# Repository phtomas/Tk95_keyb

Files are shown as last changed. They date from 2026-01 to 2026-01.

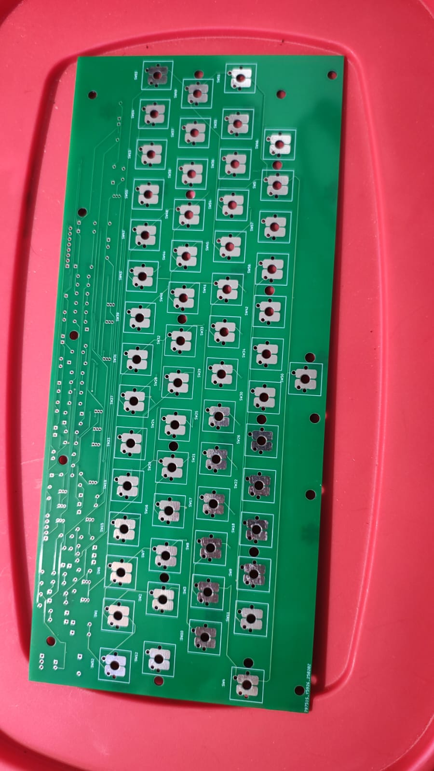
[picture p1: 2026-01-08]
keyb95_mx.jpeg

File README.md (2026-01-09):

Gerbers files to produce TK95 keyboard boards to substitute membranes. you can use original acetate and upper membrane to make contact for the keys, since at least key contact points are working. Or you can coat that points with some conduct ink or even stick some conduct material in that or use MX switches for a complete mechanical keyboard.

Based on Don Superfo schematics. original at: https://www.pcbway.com/project/shareproject/ZX_Spectrum_Keyboard_V2_14d9c665.html

Special thanks to Alexandre Simonka who has sponsered this project and Marlos Vasconcelos for moral support. Many thanks my friends.

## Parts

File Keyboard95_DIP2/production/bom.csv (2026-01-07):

Designator | Footprint | Quantity | Value | LCSC Part #
C1 | CP_Radial_D5.0mm_P2.50mm | 1 | 100uF
D1, D10, D11, D12, D13, D14, D15, D16, D17, D18, D19, D2, D20, D21, D22, D23, D24, D25, D26, D27, D28, D29, D3, D30, D31, D32, D4, D5, D6, D7, D8, D9 | D_DO-35_SOD27_P7.62mm_Horizontal | 32 | 1N4148
D33 | D_A-405_P7.62mm_Horizontal | 1 | 5v1
J1 | PinHeader_1x03_P2.54mm_Vertical | 1 | Conn_01x03_Pin
J2 | PinHeader_1x05_P2.54mm_Vertical | 1 | Conn_01x05_Pin
J3 | PinHeader_1x08_P2.54mm_Vertical | 1 | Conn_01x08_Pin
Q1, Q10, Q11P1, Q12M1, Q13N1, Q14O1, Q2, Q3, Q4, Q5, Q6, Q7, Q8, Q9 | TO-92_Inline | 14 | BC548
R1, R13, R14, R15, R16, R2, R21, R22, R23, R24, R3, R4, R5, R6 | R_Box_L8.4mm_W2.5mm_P5.08mm | 14 | 1k
R10, R11, R12, R17, R18, R19, R20, R25, R26, R27, R28, R7, R8, R9 | R_Box_L8.4mm_W2.5mm_P5.08mm | 14 | 100k
SW1 | SW_SMD_key | 1 | SW_1
SW10 | SW_SMD_key | 1 | SW_EXT
SW11 | SW_SMD_key | 1 | SW_CPLOK
SW12 | SW_SMD_key | 1 | SW_GRAPH
SW13 | SW_SMD_key | 1 | SW_TRUE
SW14 | SW_SMD_key | 1 | SW_INV
SW15 | SW_SMD_key | 1 | SW_3
SW16 | SW_SMD_key | 1 | SW_E
SW17 | SW_SMD_key | 1 | SW_D
SW18 | SW_SMD_key | 1 | SW_X
SW19 | SW_SMD_key | 1 | SW_4
SW2 | SW_SMD_key | 1 | SW_Q
SW20 | SW_SMD_key | 1 | SW_R
SW21 | SW_SMD_key | 1 | SW_F
SW22 | SW_SMD_key | 1 | SW_C
SW23 | SW_SMD_key | 1 | SW_5
SW24 | SW_SMD_key | 1 | SW_T
SW25 | SW_SMD_key | 1 | SW_G
SW26 | SW_SMD_key | 1 | SW_V
SW27 | SW_SMD_key | 1 | SW_6
SW28 | SW_SMD_key | 1 | SW_Y
SW29 | SW_SMD_key | 1 | SW_H
SW3 | SW_SMD_key | 1 | SW_A
SW30 | SW_SMD_key | 1 | SW_B
SW31 | SW_SMD_key | 1 | SW_7
SW32 | SW_SMD_key | 1 | SW_U
SW33 | SW_SMD_key | 1 | SW_J
SW34 | SW_SMD_key | 1 | SW_N
SW35 | SW_SMD_key | 1 | SW_RiGhT
SW36 | SW_SMD_key | 1 | SW_LFT
SW37 | SW_SMD_key | 1 | SW_DWN
SW38 | SW_SMD_key | 1 | SW_UP
SW39 | SW_SMD_key | 1 | SW_8
SW4, SW5 | SW_SMD_key | 2 | SW_SHFT
SW40 | SW_SMD_key | 1 | SW_I
SW41 | SW_SMD_key | 1 | SW_K
SW42 | SW_SMD_key | 1 | SW_M
SW43 | SW_SMD_key | 1 | SW_9
SW44 | SW_SMD_key | 1 | SW_O
SW45 | SW_SMD_key | 1 | SW_L
SW46 | SW_SMD_key | 1 | SW_SYMB
SW47 | SW_SMD_key | 1 | SW_0
SW48 | SW_SMD_key | 1 | SW_P
SW49 | SW_SMD_key | 1 | SW_ENT
SW50 | SW_SMD_key | 1 | SW_SPC
SW51 | SW_SMD_key | 1 | SW_DEL
SW52 | SW_SMD_key | 1 | SW_EDT
SW53 | SW_SMD_key | 1 | SW_BRK
SW54 | SW_SMD_key | 1 | SW_dotvirg
SW55 | SW_SMD_key | 1 | SW_asp
SW56 | SW_SMD_key | 1 | SW_dot
SW57 | SW_SMD_key | 1 | SW_virg
SW6 | SW_SMD_key | 1 | SW_2
SW7 | SW_SMD_key | 1 | SW_W
SW8 | SW_SMD_key | 1 | SW_S
SW9 | SW_SMD_key | 1 | SW_Z

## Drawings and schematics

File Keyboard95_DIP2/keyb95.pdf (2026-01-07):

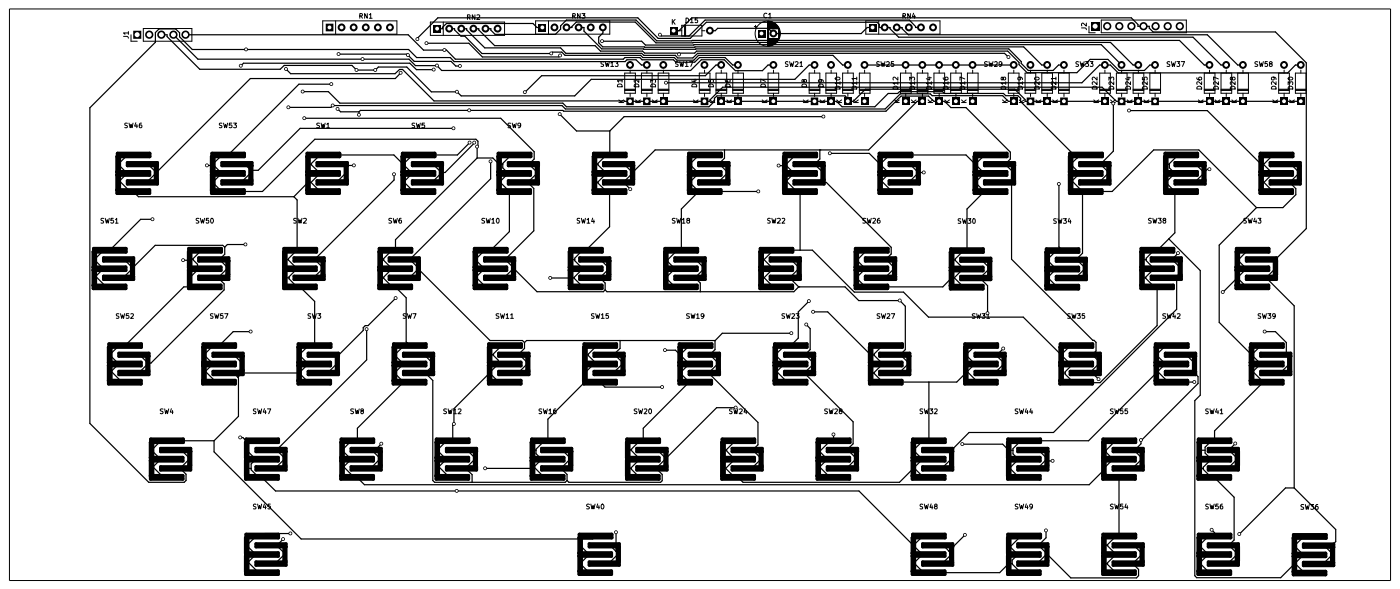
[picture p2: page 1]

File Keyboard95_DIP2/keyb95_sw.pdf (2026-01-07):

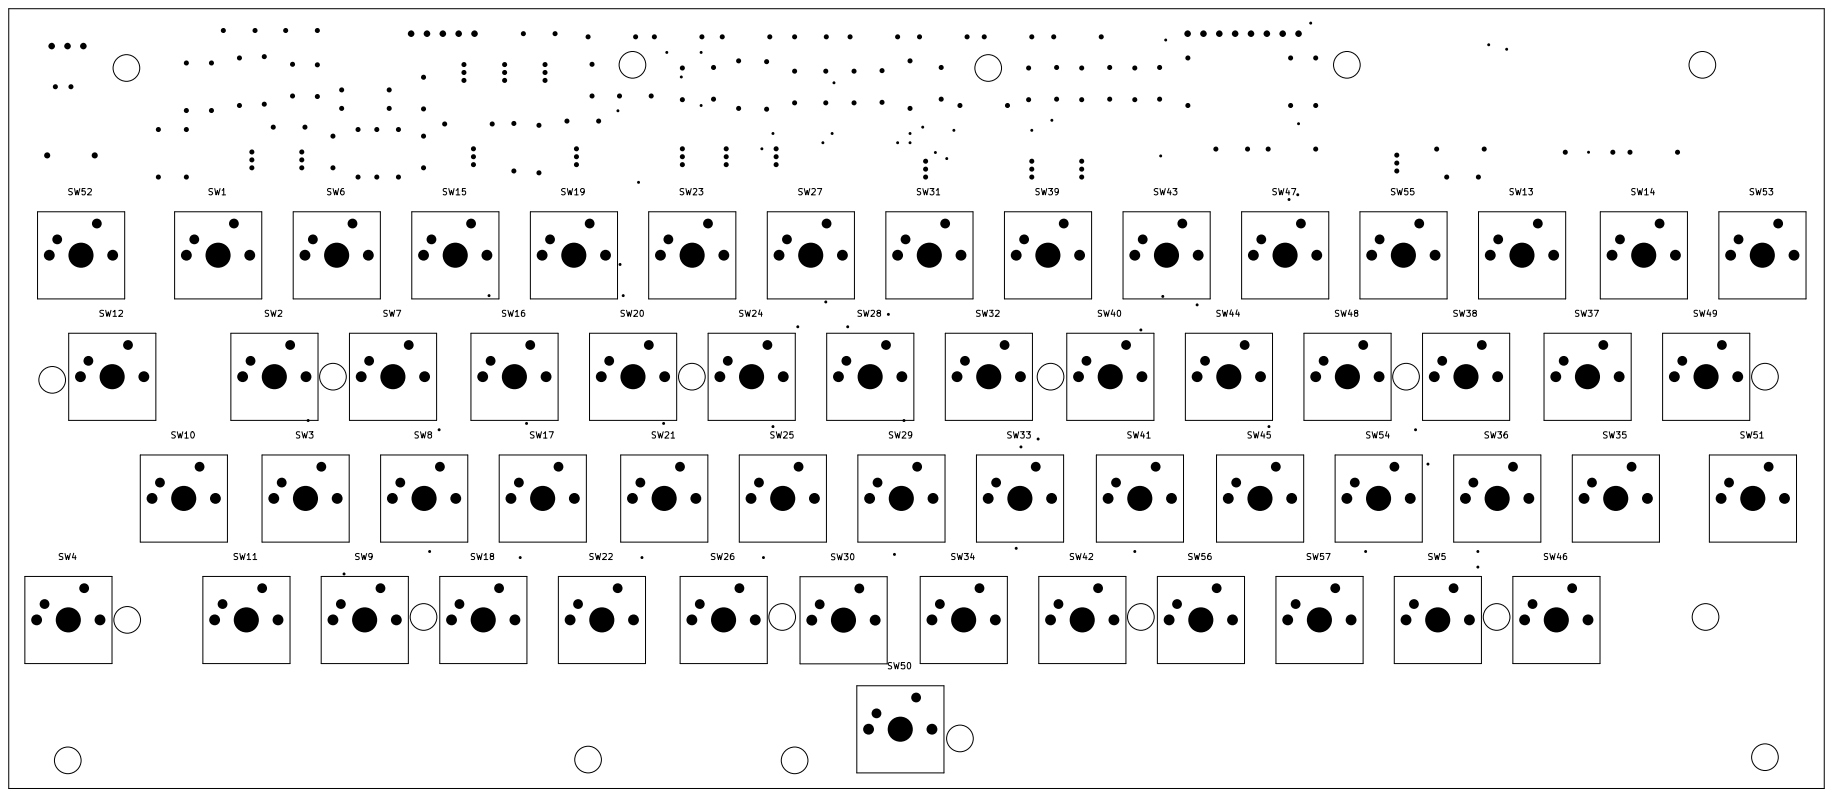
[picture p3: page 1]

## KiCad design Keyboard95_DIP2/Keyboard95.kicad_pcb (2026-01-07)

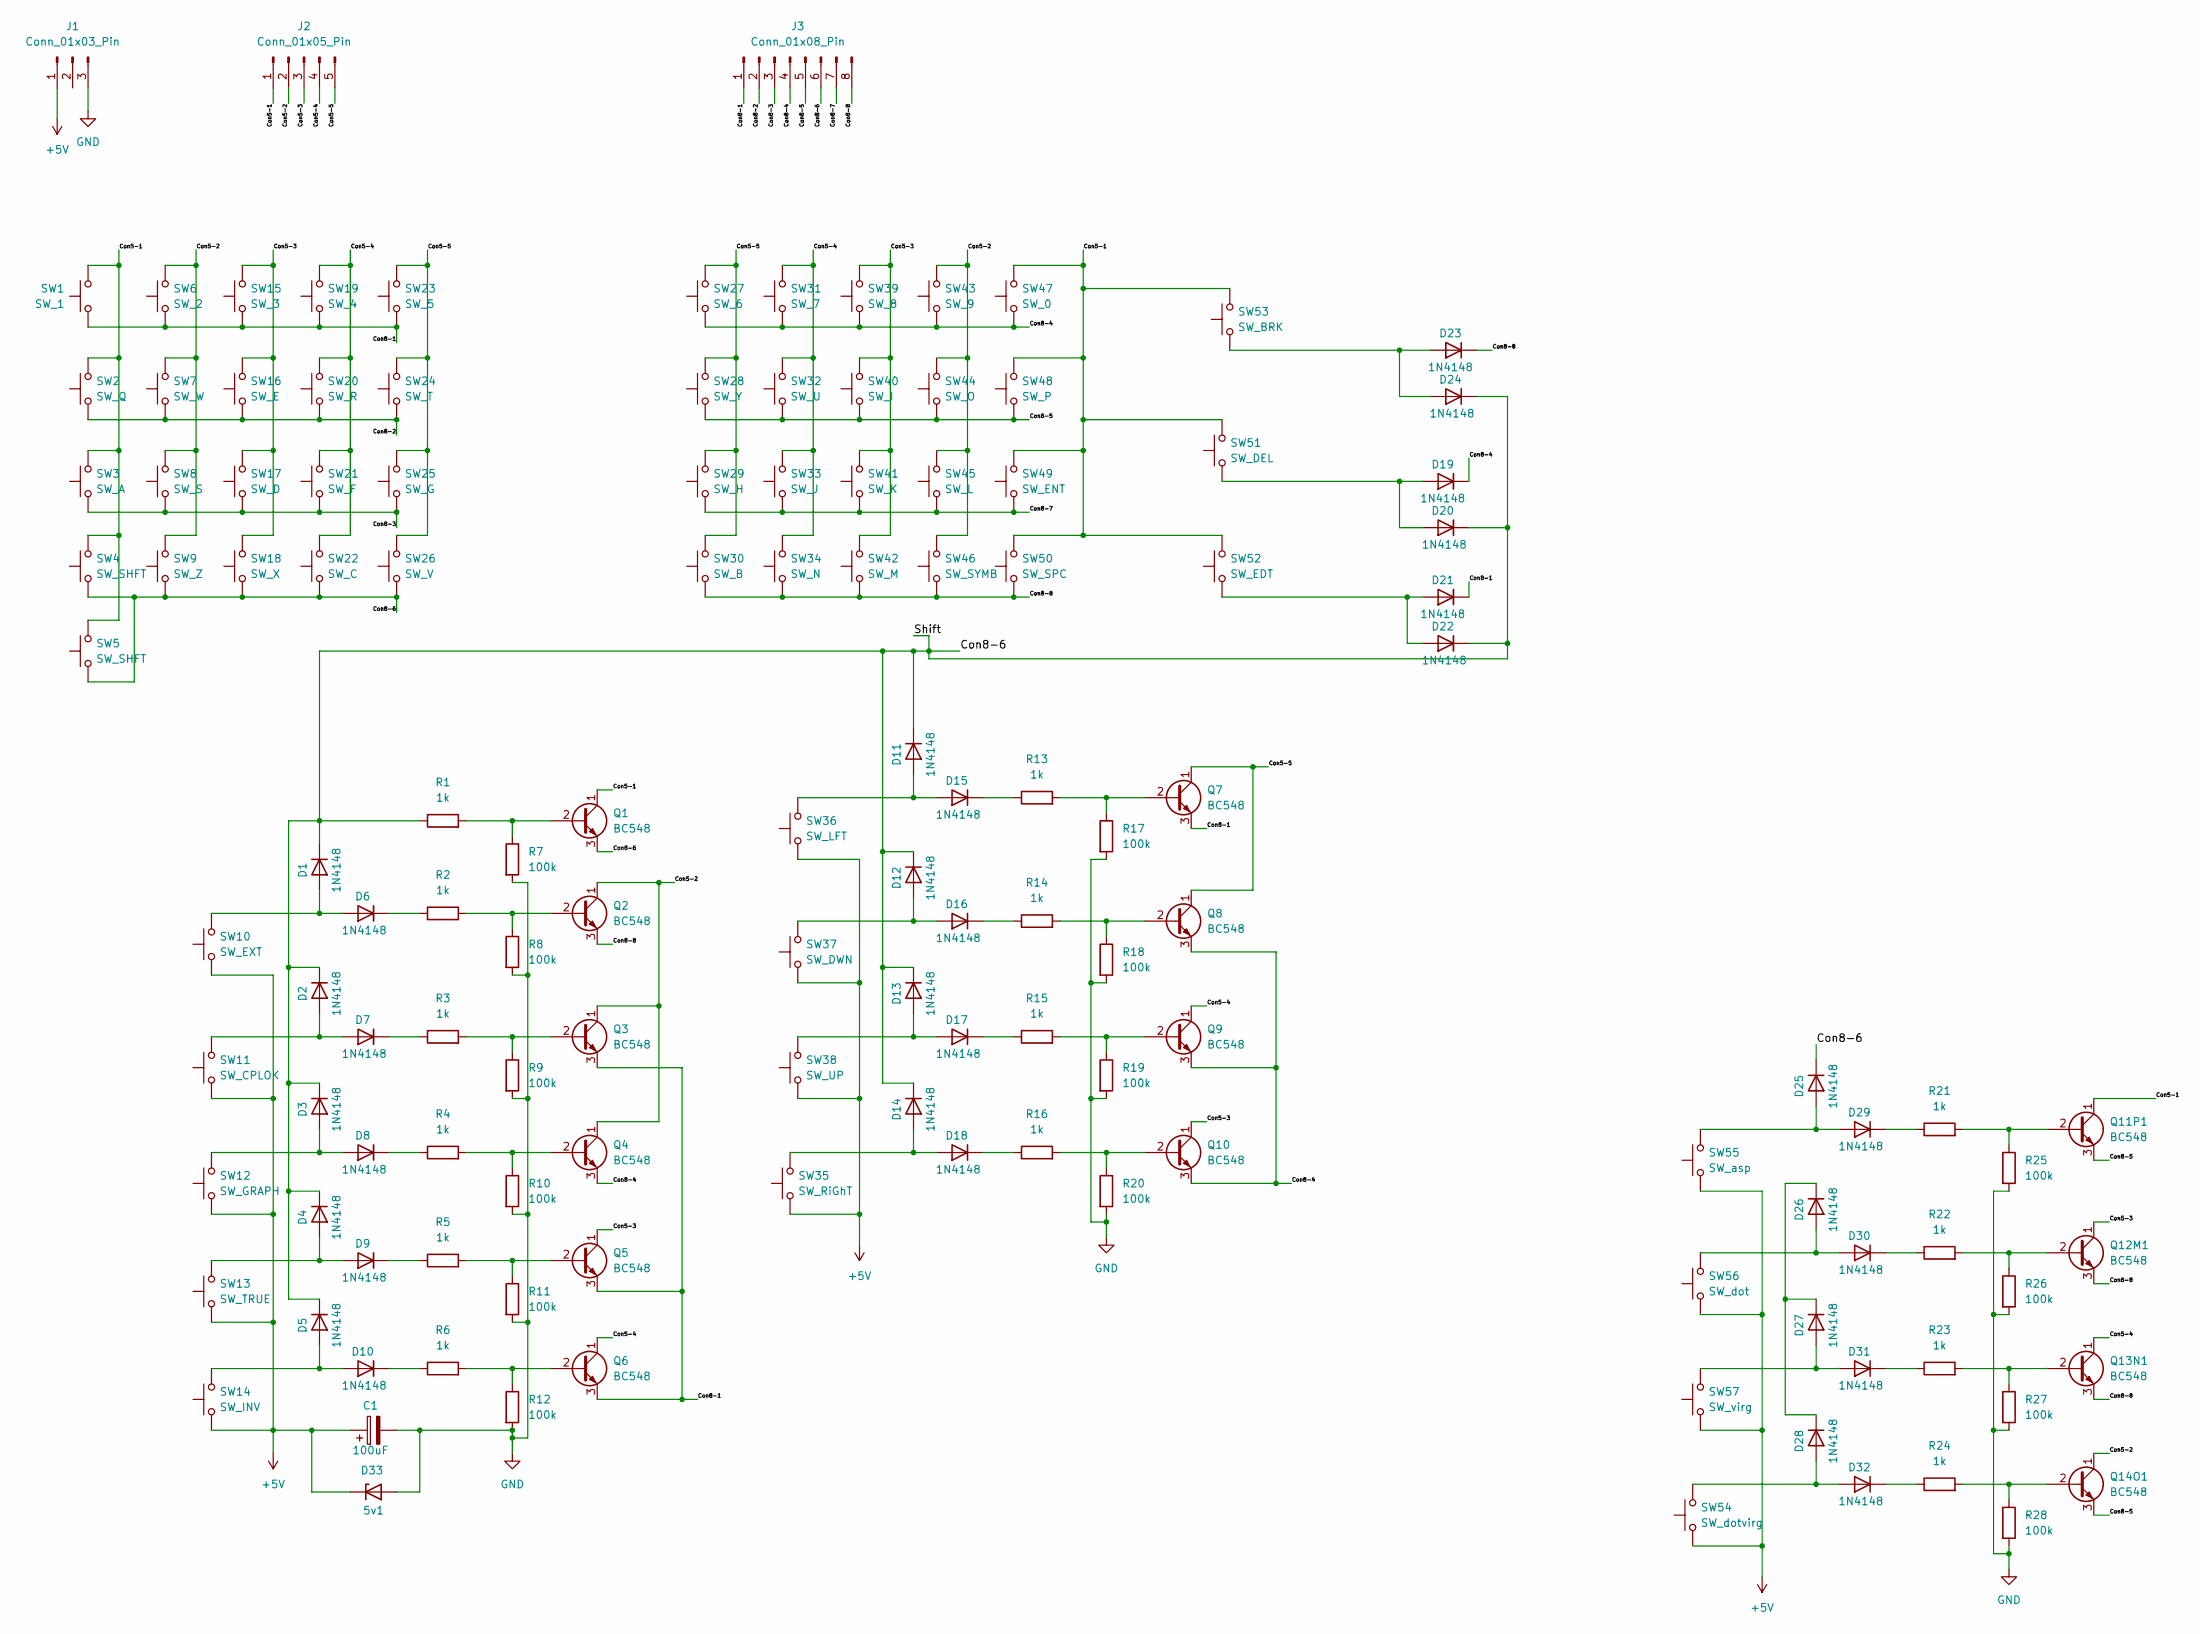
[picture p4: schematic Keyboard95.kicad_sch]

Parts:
C1: 100uF; CP_Radial_D5.0mm_P2.50mm
D1, D2, D3, D4, D5, D6, D7, D8, D9, D10, D11, D12, D13, D14, D15, D16, D17, D18, D19, D20, D21, D22, D23, D24, D25, D26, D27, D28, D29, D30, D31, D32: 1N4148; D_DO-35_SOD27_P7.62mm_Horizontal
D33: 5v1; D_A-405_P7.62mm_Horizontal
J1: Conn_01x03_Pin; PinHeader_1x03_P2.54mm_Vertical
J2: Conn_01x05_Pin; PinHeader_1x05_P2.54mm_Vertical
J3: Conn_01x08_Pin; PinHeader_1x08_P2.54mm_Vertical
Q1, Q2, Q3, Q4, Q5, Q6, Q7, Q8, Q9, Q10, Q11P1, Q12M1, Q13N1, Q14O1: BC548; TO-92_Inline
R1, R2, R3, R4, R5, R6, R13, R14, R15, R16, R21, R22, R23, R24: 1k; R_Box_L8.4mm_W2.5mm_P5.08mm
R7, R8, R9, R10, R11, R12, R17, R18, R19, R20, R25, R26, R27, R28: 100k; R_Box_L8.4mm_W2.5mm_P5.08mm
SW1: SW_1; SW_SMD_key
SW2: SW_Q; SW_SMD_key
SW3: SW_A; SW_SMD_key
SW4, SW5: SW_SHFT; SW_SMD_key
SW6: SW_2; SW_SMD_key
SW7: SW_W; SW_SMD_key
SW8: SW_S; SW_SMD_key
SW9: SW_Z; SW_SMD_key
SW10: SW_EXT; SW_SMD_key
SW11: SW_CPLOK; SW_SMD_key
SW12: SW_GRAPH; SW_SMD_key
SW13: SW_TRUE; SW_SMD_key
SW14: SW_INV; SW_SMD_key
SW15: SW_3; SW_SMD_key
SW16: SW_E; SW_SMD_key
SW17: SW_D; SW_SMD_key
SW18: SW_X; SW_SMD_key
SW19: SW_4; SW_SMD_key
SW20: SW_R; SW_SMD_key
SW21: SW_F; SW_SMD_key
SW22: SW_C; SW_SMD_key
SW23: SW_5; SW_SMD_key
SW24: SW_T; SW_SMD_key
SW25: SW_G; SW_SMD_key
SW26: SW_V; SW_SMD_key
SW27: SW_6; SW_SMD_key
SW28: SW_Y; SW_SMD_key
SW29: SW_H; SW_SMD_key
SW30: SW_B; SW_SMD_key
SW31: SW_7; SW_SMD_key
SW32: SW_U; SW_SMD_key
SW33: SW_J; SW_SMD_key
SW34: SW_N; SW_SMD_key
SW35: SW_RiGhT; SW_SMD_key
SW36: SW_LFT; SW_SMD_key
SW37: SW_DWN; SW_SMD_key
SW38: SW_UP; SW_SMD_key
SW39: SW_8; SW_SMD_key
SW40: SW_I; SW_SMD_key
SW41: SW_K; SW_SMD_key
SW42: SW_M; SW_SMD_key
SW43: SW_9; SW_SMD_key
SW44: SW_O; SW_SMD_key
SW45: SW_L; SW_SMD_key
SW46: SW_SYMB; SW_SMD_key
SW47: SW_0; SW_SMD_key
SW48: SW_P; SW_SMD_key
SW49: SW_ENT; SW_SMD_key
SW50: SW_SPC; SW_SMD_key
SW51: SW_DEL; SW_SMD_key
SW52: SW_EDT; SW_SMD_key
SW53: SW_BRK; SW_SMD_key
SW54: SW_dotvirg; SW_SMD_key
SW55: SW_asp; SW_SMD_key
SW56: SW_dot; SW_SMD_key
SW57: SW_virg; SW_SMD_key

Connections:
+5V: C1.1, D33.1 (K), J1.1, SW10.1, SW11.1, SW12.1, SW13.1, SW14.1, SW35.1, SW36.1, SW37.1, SW38.1, SW54.1, SW55.1, SW56.1, SW57.1
/Con5-1: J2.1, Q1.1 (C), Q11P1.1 (C), SW1.2, SW2.2, SW3.2, SW4.2, SW5.2, SW47.2, SW48.2, SW49.2, SW50.2, SW51.2, SW52.2, SW53.2
/Con5-2: J2.2, Q2.1 (C), Q3.1 (C), Q4.1 (C), Q14O1.1 (C), SW6.2, SW7.2, SW8.2, SW9.2, SW43.2, SW44.2, SW45.2, SW46.2
/Con5-3: J2.3, Q5.1 (C), Q10.1 (C), Q12M1.1 (C), SW15.2, SW16.2, SW17.2, SW18.2, SW39.2, SW40.2, SW41.2, SW42.2
/Con5-4: J2.4, Q6.1 (C), Q9.1 (C), Q13N1.1 (C), SW19.2, SW20.2, SW21.2, SW22.2, SW31.2, SW32.2, SW33.2, SW34.2
/Con5-5: J2.5, Q7.1 (C), Q8.1 (C), SW23.2, SW24.2, SW25.2, SW26.2, SW27.2, SW28.2, SW29.2, SW30.2
/Con8-1: D21.1 (K), J3.1, Q3.3 (E), Q5.3 (E), Q6.3 (E), Q7.3 (E), SW1.1, SW6.1, SW15.1, SW19.1, SW23.1
/Con8-2: J3.2, SW2.1, SW7.1, SW16.1, SW20.1, SW24.1
/Con8-3: J3.3, SW3.1, SW8.1, SW17.1, SW21.1, SW25.1
/Con8-4: D19.1 (K), J3.4, Q4.3 (E), Q8.3 (E), Q9.3 (E), Q10.3 (E), SW27.1, SW31.1, SW39.1, SW43.1, SW47.1
/Con8-5: J3.5, Q11P1.3 (E), Q14O1.3 (E), SW28.1, SW32.1, SW40.1, SW44.1, SW48.1
/Con8-6: D1.1 (K), D2.1 (K), D3.1 (K), D4.1 (K), D5.1 (K), D11.1 (K), D12.1 (K), D13.1 (K), D14.1 (K), D20.1 (K), D22.1 (K), D24.1 (K), D25.1 (K), J3.6, Q1.3 (E), R1.1, SW4.1, SW5.1, SW9.1, SW18.1, SW22.1, SW26.1
/Con8-7: J3.7, SW29.1, SW33.1, SW41.1, SW45.1, SW49.1
/Con8-8: D23.1 (K), J3.8, Q2.3 (E), Q12M1.3 (E), Q13N1.3 (E), SW30.1, SW34.1, SW42.1, SW46.1, SW50.1
GND: C1.2, D33.2 (A), J1.3, R7.2, R8.2, R9.2, R10.2, R11.2, R12.2, R17.2, R18.2, R19.2, R20.2, R25.2, R26.2, R27.2, R28.2
unnamed: D1.2 (A), D6.2 (A), SW10.2
unnamed: D2.2 (A), D7.2 (A), SW11.2
unnamed: D3.2 (A), D8.2 (A), SW12.2
unnamed: D4.2 (A), D9.2 (A), SW13.2
unnamed: D6.1 (K), R2.1
unnamed: D7.1 (K), R3.1
unnamed: D8.1 (K), R4.1
unnamed: D9.1 (K), R5.1
unnamed: D5.2 (A), D10.2 (A), SW14.2
unnamed: D10.1 (K), R6.1
unnamed: D11.2 (A), D15.2 (A), SW36.2
unnamed: D12.2 (A), D16.2 (A), SW37.2
unnamed: D13.2 (A), D17.2 (A), SW38.2
unnamed: D14.2 (A), D18.2 (A), SW35.2
unnamed: D15.1 (K), R13.1
unnamed: D16.1 (K), R14.1
unnamed: D17.1 (K), R15.1
unnamed: D18.1 (K), R16.1
unnamed: D19.2 (A), D20.2 (A), SW51.1
unnamed: D21.2 (A), D22.2 (A), SW52.1
unnamed: D23.2 (A), D24.2 (A), SW53.1
unnamed: D25.2 (A), D29.2 (A), SW55.2
unnamed: D26.2 (A), D30.2 (A), SW56.2
unnamed: D26.1 (K), D27.1 (K), D28.1 (K)
unnamed: D27.2 (A), D31.2 (A), SW57.2
unnamed: D28.2 (A), D32.2 (A), SW54.2
unnamed: D29.1 (K), R21.1
unnamed: D30.1 (K), R22.1
unnamed: D31.1 (K), R23.1
unnamed: D32.1 (K), R24.1
unnamed: Q1.2 (B), R1.2, R7.1
unnamed: Q2.2 (B), R2.2, R8.1
unnamed: Q3.2 (B), R3.2, R9.1
unnamed: Q4.2 (B), R4.2, R10.1
unnamed: Q5.2 (B), R5.2, R11.1
unnamed: Q6.2 (B), R6.2, R12.1
unnamed: Q7.2 (B), R13.2, R17.1
unnamed: Q8.2 (B), R14.2, R18.1
unnamed: Q9.2 (B), R15.2, R19.1
unnamed: Q10.2 (B), R16.2, R20.1
unnamed: Q11P1.2 (B), R21.2, R25.1
unnamed: Q12M1.2 (B), R22.2, R26.1
unnamed: Q13N1.2 (B), R23.2, R27.1
unnamed: Q14O1.2 (B), R24.2, R28.1

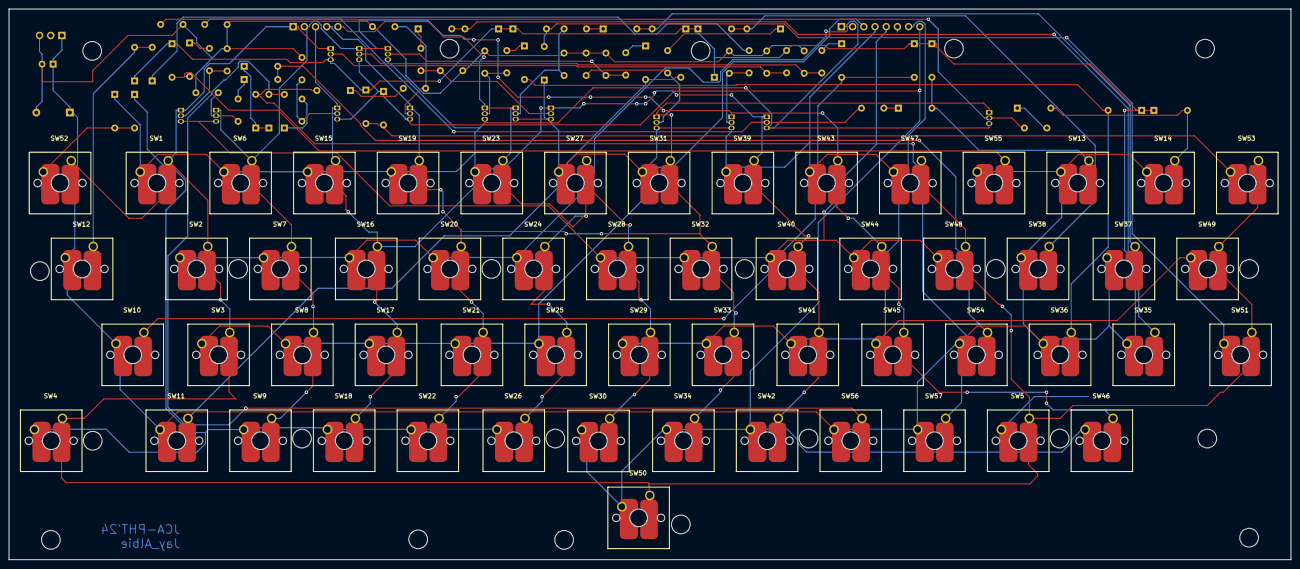
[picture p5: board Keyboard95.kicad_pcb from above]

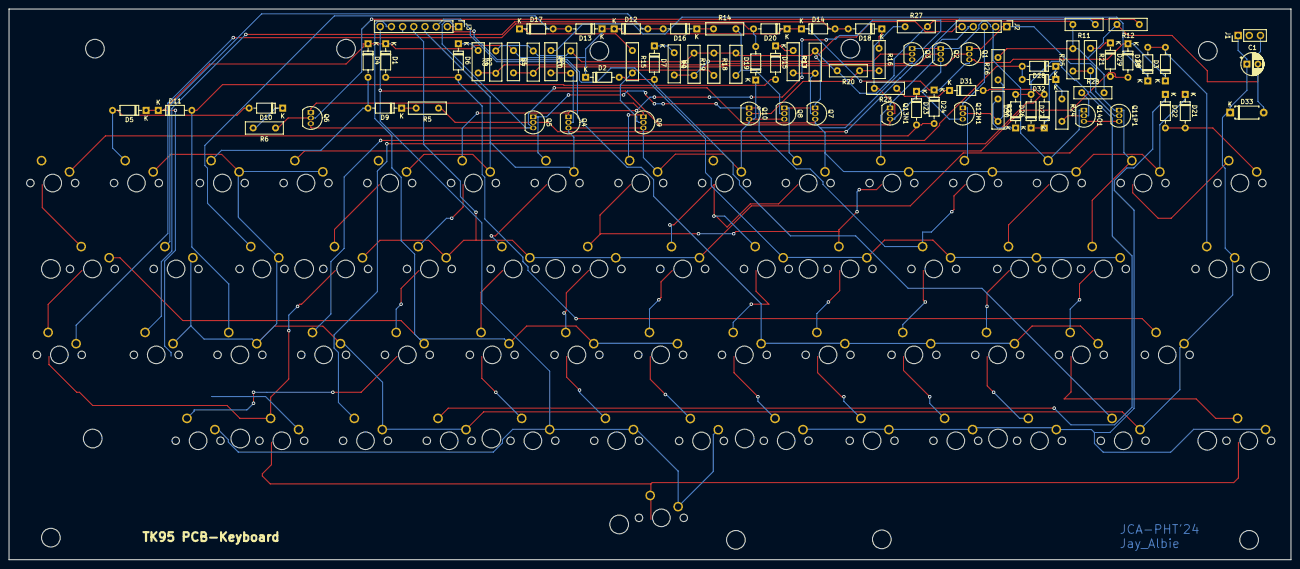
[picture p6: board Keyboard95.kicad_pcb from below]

Board: 2 copper layers, 291.0 x 125.0 mm, 136 parts (79 on the bottom side), 59 nets.

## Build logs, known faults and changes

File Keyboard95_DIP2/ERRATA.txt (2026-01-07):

1- cortar trilha D22 para D3, conector 8-6 e 1 de SW5
2- levantar Emissor de Q1, K de D24 e D20
3- conectar K de D22 aos K de D20, D24, Emissor de Q1 e conector de 8-6
4- conectar 1 de SW5 a conector 8-6
5- conectar K de D28 a K de D3
